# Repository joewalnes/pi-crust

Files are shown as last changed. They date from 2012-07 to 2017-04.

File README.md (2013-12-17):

Pi Crust
========

This is a PCB that brings sanity to Raspberry Pi headers.

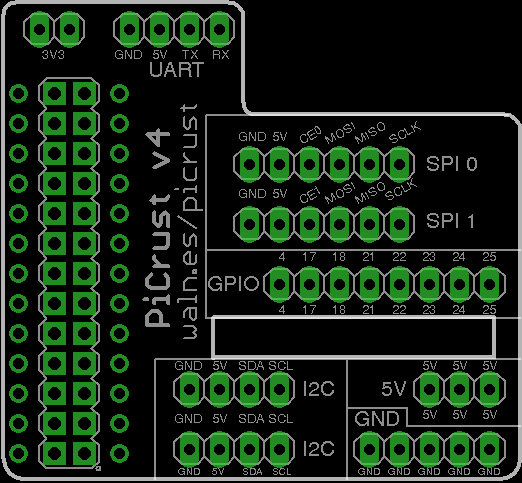
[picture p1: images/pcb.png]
Pi Crust PCB Layout


See [http://picru.st](http://picru.st) for more.

Features
--------

*   Really compact - sits *inside* the surface area of the Raspberry Pi and adds less than 2mm to the height. If you have a case for your Raspberry Pi, this board should fit inside it.
*   Pins are grouped together: GPIO, I2C, SPI, UART and power.
*   Every pin is clearly labelled.
*   Connections: 2 x SPI, 2 x I2C, 1 x UART, 8 x GPIO
*   Uses female headers instead of male headers - you can poke jumpers right in.
*   Lots of GND and 5V pins - you need those guys a lot. These pins are duplicated where it makes sense (e.g. within the UART, I2C and SPI groups).
*   All thru-hole components - you can solder it yourself.
*   Cheapety cheapy cheap.
*   Open source hardware.
*   [More photos here](http://todayimade.co/items/joe-walnes-made-a-tiny-breakout-board-for-raspberry-pi)

See [http://picru.st](http://picru.st) for more.

Bitdeli Badge (https://bitdeli.com/free "Bitdeli Badge")

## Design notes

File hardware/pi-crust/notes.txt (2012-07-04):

01: 3.3V (50 mA max)
02: 5V
06: GND

07: GPIO 4 (GPCLCK0)
11: GPIO 17
12: GPIO 18 (PWM)
13: GPIO 21
15: GPIO 22
16: GPIO 23
18: GPIO 24
22: GPIO 25

== I2C * 2 == order: g, 5v, sda, scl	
03: I2C SDA / GPIO 0
05: I2C SCL / GPIO 1

== UART . order: g, 5v, tx, rx
08: TX / GPIO 14
10: RX / GPIO 15

== SPI * 2 Select (g, v, CE1/CE0, mosi, miso, sclk)
26: SPI CE1_N / GPIO 7
24: SPI CE0_N / GPIO 8
21: SPI MISO / GPIO 9
19: SPI MOSI / GPIO 10
23: SPI SCLK / GPIO 11

04: DNC
09: DNC
14: DNC
17: DNC
20: DNC
25: DNC

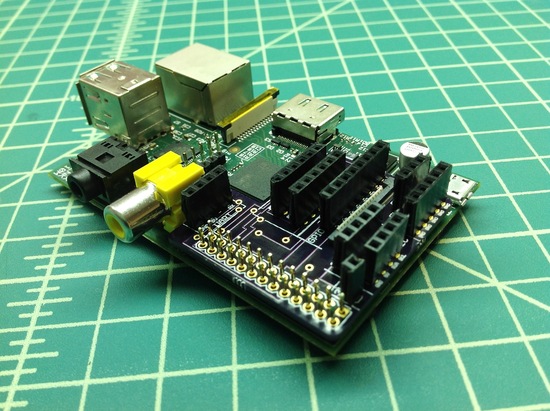
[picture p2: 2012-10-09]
images/prototype.jpg

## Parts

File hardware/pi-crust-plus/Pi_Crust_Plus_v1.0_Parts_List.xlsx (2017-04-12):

Part | Manufacturer | Quantity | Comment
MDF7-26D-2.54DSA(55) | Hirose | 1
40 pin 2.54mm female header |  | 1 | Plastic height - 8mm, metal height 8mm, square pins 0.64mm
1x2 2.54mm female header |  | 2
1x4 2.54mm female header |  | 5
1x6 2.54mm female header |  | 2
1x8 2.54mm female header |  | 1
1x9 2.54mm female header |  | 1
1x2 2.54mm male header |  | 1

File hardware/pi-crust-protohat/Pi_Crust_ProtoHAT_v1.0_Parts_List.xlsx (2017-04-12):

Part | Value | Device | Package
C1 | 100nF | C-EUC0805K | C0805K
CFG | 2 pin jumper, 2.54mm | PIN2_100 | PIN_W_2
R1 | 3k9 | R-EU_M0805 | M0805
R2 | 3k9 | R-EU_M0805 | M0805
R3 | 1k | R-EU_M0805 | M0805
U1 | CAT24C32 | EEPROM24 | SOIC8
Header | 10724 from www.4uconnector.com
Shunt for CFG | 2.54mm 2 pin shunt

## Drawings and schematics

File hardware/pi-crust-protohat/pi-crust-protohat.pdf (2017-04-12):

A

A

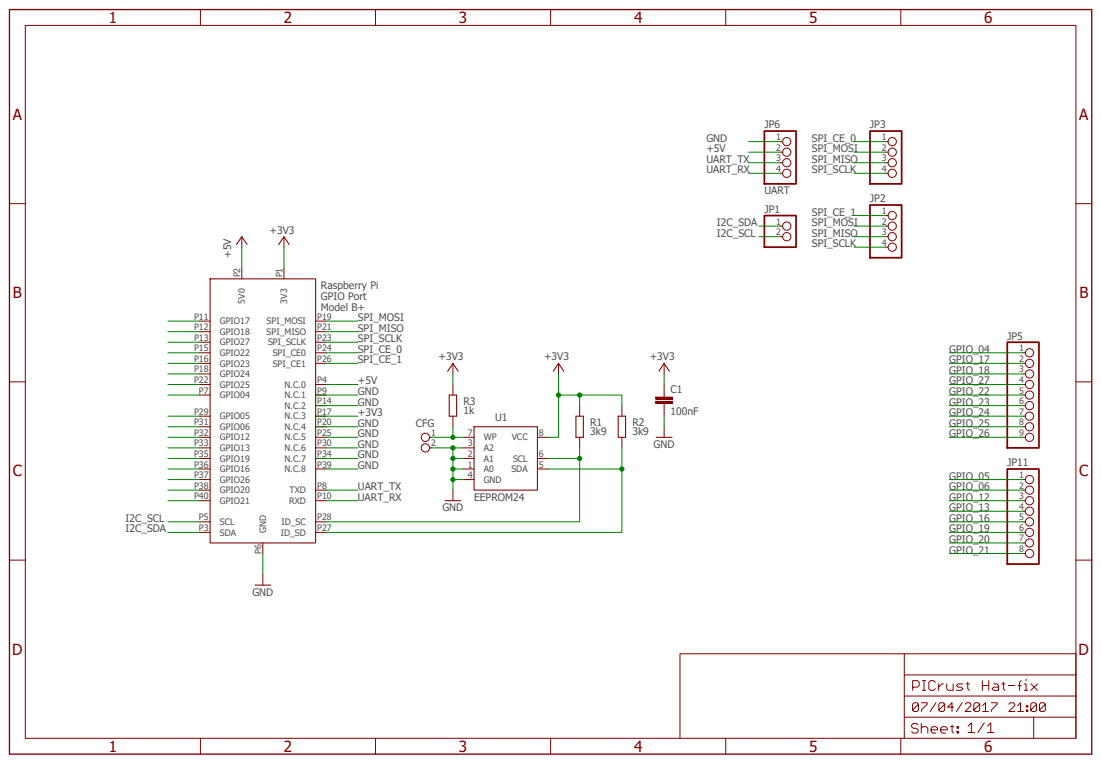
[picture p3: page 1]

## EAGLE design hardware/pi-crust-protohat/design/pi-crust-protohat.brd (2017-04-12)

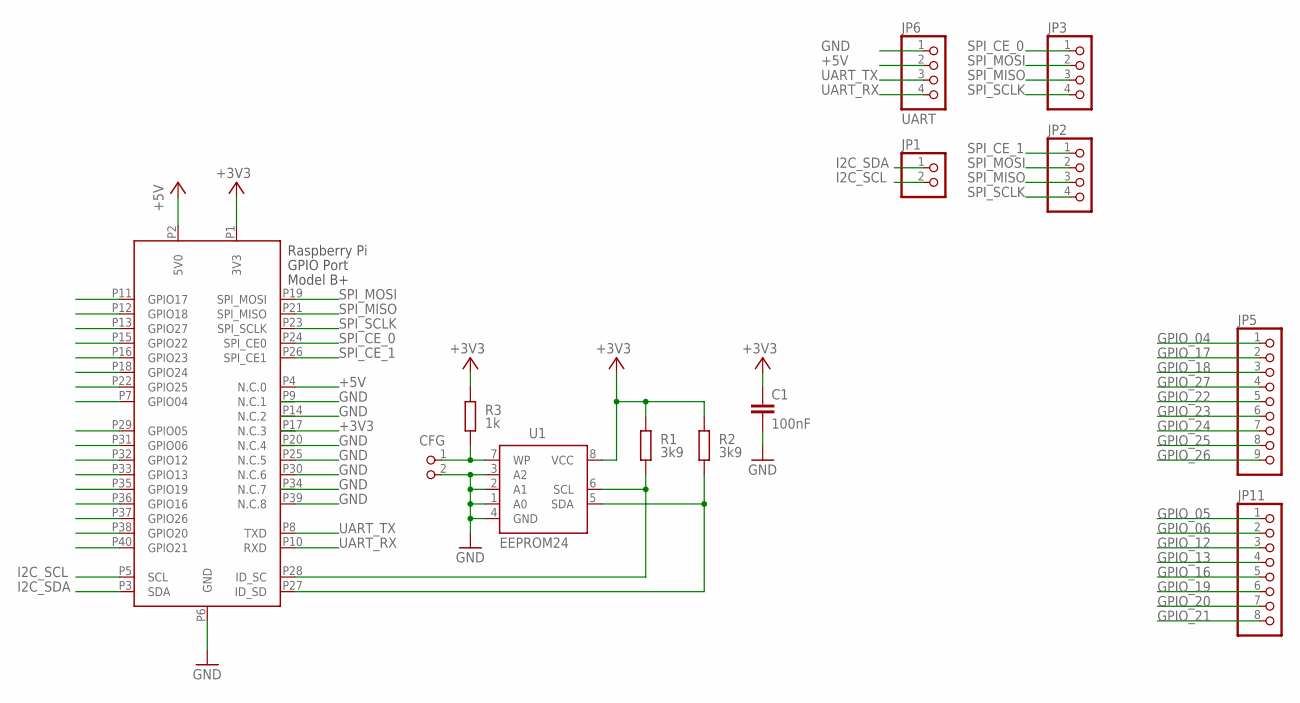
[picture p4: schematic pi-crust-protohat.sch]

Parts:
C1: 100nF; C0805K
CFG: PIN2_100; PIN_W_2
JP1: PINHD-1X2; 1X02
JP2, JP3: PINHD-1X4; 1X04
JP5: PINHD-1X9; 1X09
JP6: UART; 1X04
JP11: PINHD-1X8; 1X08
R1, R2: 3k9; M0805; TOLERANCE 5%
R3: 1k; M0805; TOLERANCE 5%
U1: EEPROM24; SOIC8
U$1: RASPI_BOARD_B+_SMD; RASPI_BOARD_B+_SMD_CONNECTOR

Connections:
+3V3: C1.1, R1.2, R2.2, R3.2, U1.8 (VCC), U$1.P1 (3V3)
+5V: JP6.2, U$1.P2 (5V0), U$1.P4 (N.C.0)
GND: C1.2, CFG.2, JP6.1, U1.1 (A0), U1.2 (A1), U1.3 (A2), U1.4 (GND), U$1.P6 (GND), U$1.P25 (N.C.5), U$1.P30 (N.C.6), U$1.P39 (N.C.8)
GPIO_04: JP5.1, U$1.P7 (GPIO04)
GPIO_05: JP11.1, U$1.P29 (GPIO05)
GPIO_06: JP11.2, U$1.P31 (GPIO06)
GPIO_12: JP11.3, U$1.P32 (GPIO12)
GPIO_13: JP11.4, U$1.P33 (GPIO13)
GPIO_16: JP11.5, U$1.P36 (GPIO16)
GPIO_17: JP5.2, U$1.P11 (GPIO17)
GPIO_18: JP5.3, U$1.P12 (GPIO18)
GPIO_19: JP11.6, U$1.P35 (GPIO19)
GPIO_20: JP11.7, U$1.P38 (GPIO20)
GPIO_21: JP11.8, U$1.P40 (GPIO21)
GPIO_22: JP5.5, U$1.P15 (GPIO22)
GPIO_23: JP5.6, U$1.P16 (GPIO23)
GPIO_24: JP5.7, U$1.P18 (GPIO24)
GPIO_25: JP5.8, U$1.P22 (GPIO25)
GPIO_26: JP5.9, U$1.P37 (GPIO26)
GPIO_27: JP5.4, U$1.P13 (GPIO27)
I2C_SCL: JP1.2, U$1.P5 (SCL)
I2C_SDA: JP1.1, U$1.P3 (SDA)
unnamed: CFG.1, R3.1, U1.7 (WP)
unnamed: R1.1, U1.6 (SCL), U$1.P28 (ID_SC)
unnamed: R2.1, U1.5 (SDA), U$1.P27 (ID_SD)
SPI_CE_0: JP3.1, U$1.P24 (SPI_CE0)
SPI_CE_1: JP2.1, U$1.P26 (SPI_CE1)
SPI_MISO: JP2.3, JP3.3, U$1.P21 (SPI_MISO)
SPI_MOSI: JP2.2, JP3.2, U$1.P19 (SPI_MOSI)
SPI_SCLK: JP2.4, JP3.4, U$1.P23 (SPI_SCLK)
UART_RX: JP6.4, U$1.P10 (RXD)
UART_TX: JP6.3, U$1.P8 (TXD)

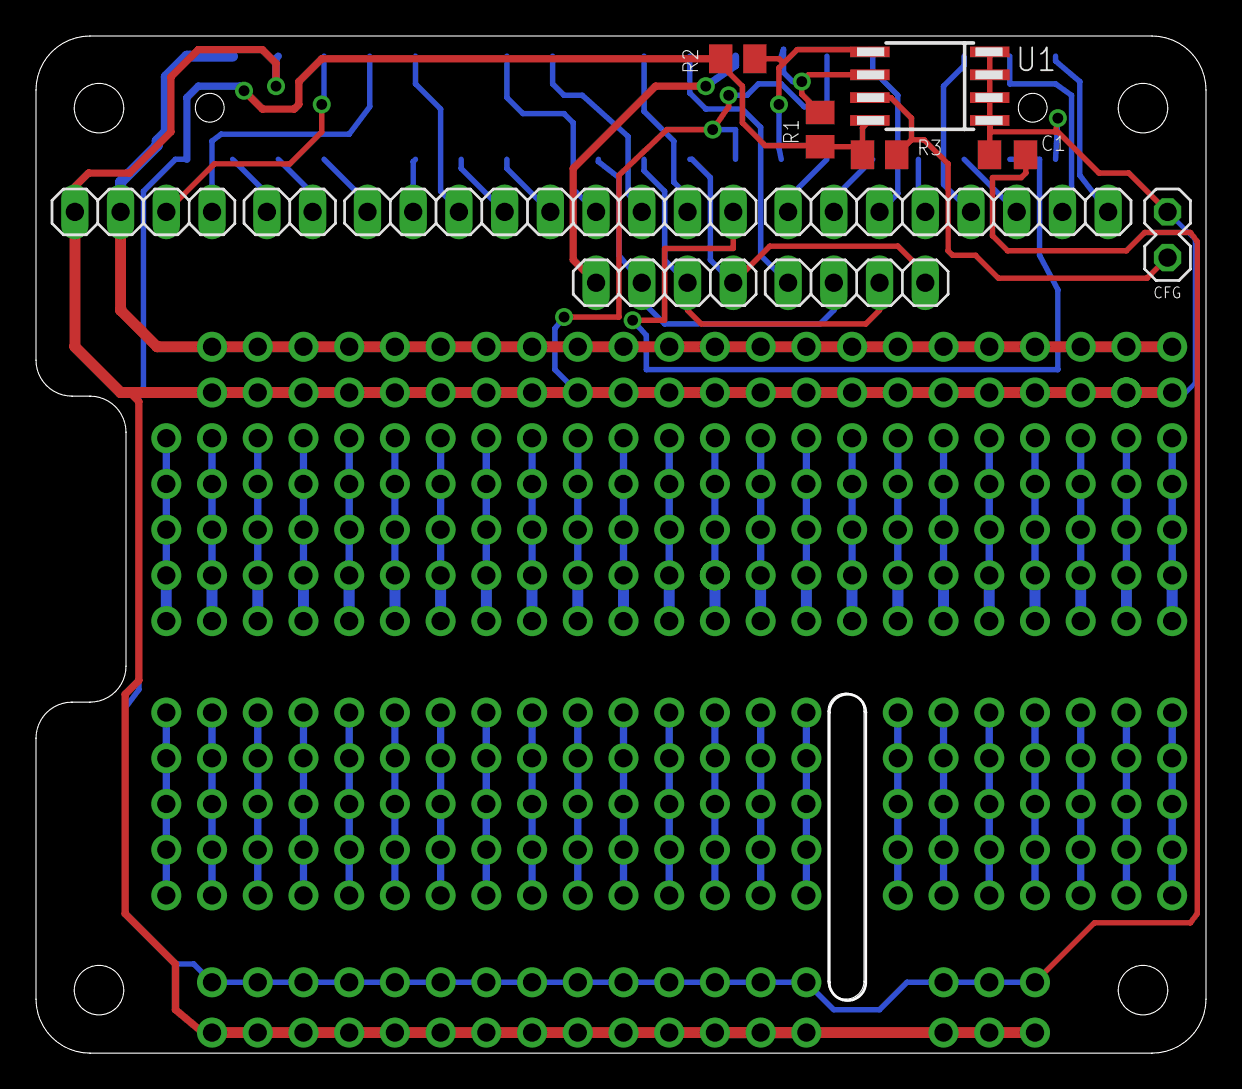
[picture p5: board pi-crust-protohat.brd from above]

Board: 2 copper layers, 65.0 x 56.5 mm, 13 parts (0 on the bottom side), 32 nets.

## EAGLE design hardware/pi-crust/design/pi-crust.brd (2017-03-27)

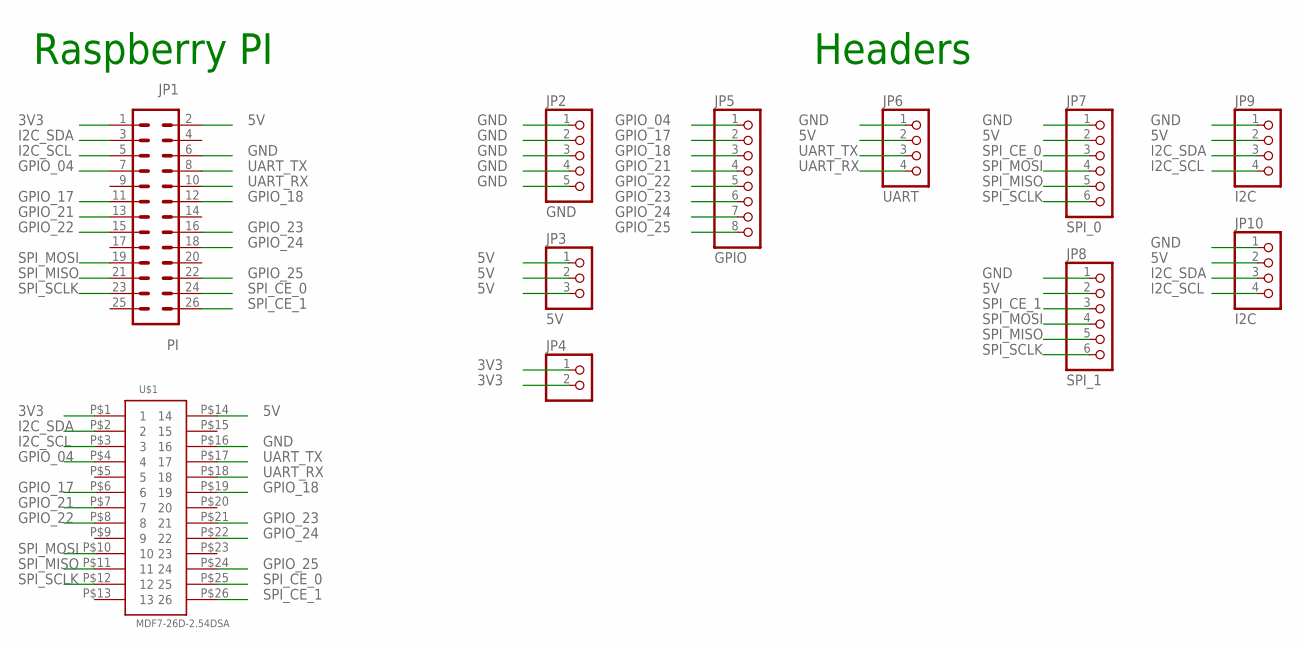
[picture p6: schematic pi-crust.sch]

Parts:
JP1: PI; MA13-2
JP2: GND; 1X05
JP3: 5V; 1X03
JP4: PINHD-1X2; 1X02
JP5: GPIO; 1X08
JP6: UART; 1X04
JP7: SPI_0; 1X06
JP8: SPI_1; 1X06
JP9, JP10: I2C; 1X04
U$1: MDF7-26D-2.54DSA

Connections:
3V3: JP1.1, JP4.1, JP4.2, U$1.P$1 (1)
5V: JP1.2, JP3.1, JP3.2, JP3.3, JP6.2, JP7.2, JP8.2, JP9.2, JP10.2, U$1.P$14 (14)
GND: JP1.6, JP2.1, JP2.2, JP2.3, JP2.4, JP2.5, JP6.1, JP7.1, JP8.1, JP9.1, JP10.1, U$1.P$16 (16)
GPIO_04: JP1.7, JP5.1, U$1.P$4 (4)
GPIO_17: JP1.11, JP5.2, U$1.P$6 (6)
GPIO_18: JP1.12, JP5.3, U$1.P$19 (19)
GPIO_21: JP1.13, JP5.4, U$1.P$7 (7)
GPIO_22: JP1.15, JP5.5, U$1.P$8 (8)
GPIO_23: JP1.16, JP5.6, U$1.P$21 (21)
GPIO_24: JP1.18, JP5.7, U$1.P$22 (22)
GPIO_25: JP1.22, JP5.8, U$1.P$24 (24)
I2C_SCL: JP1.5, JP9.4, JP10.4, U$1.P$3 (3)
I2C_SDA: JP1.3, JP9.3, JP10.3, U$1.P$2 (2)
SPI_CE_0: JP1.24, JP7.3, U$1.P$25 (25)
SPI_CE_1: JP1.26, JP8.3, U$1.P$26 (26)
SPI_MISO: JP1.21, JP7.5, JP8.5, U$1.P$11 (11)
SPI_MOSI: JP1.19, JP7.4, JP8.4, U$1.P$10 (10)
SPI_SCLK: JP1.23, JP7.6, JP8.6, U$1.P$12 (12)
UART_RX: JP1.10, JP6.4, U$1.P$18 (18)
UART_TX: JP1.8, JP6.3, U$1.P$17 (17)

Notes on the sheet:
Raspberry PI
Headers

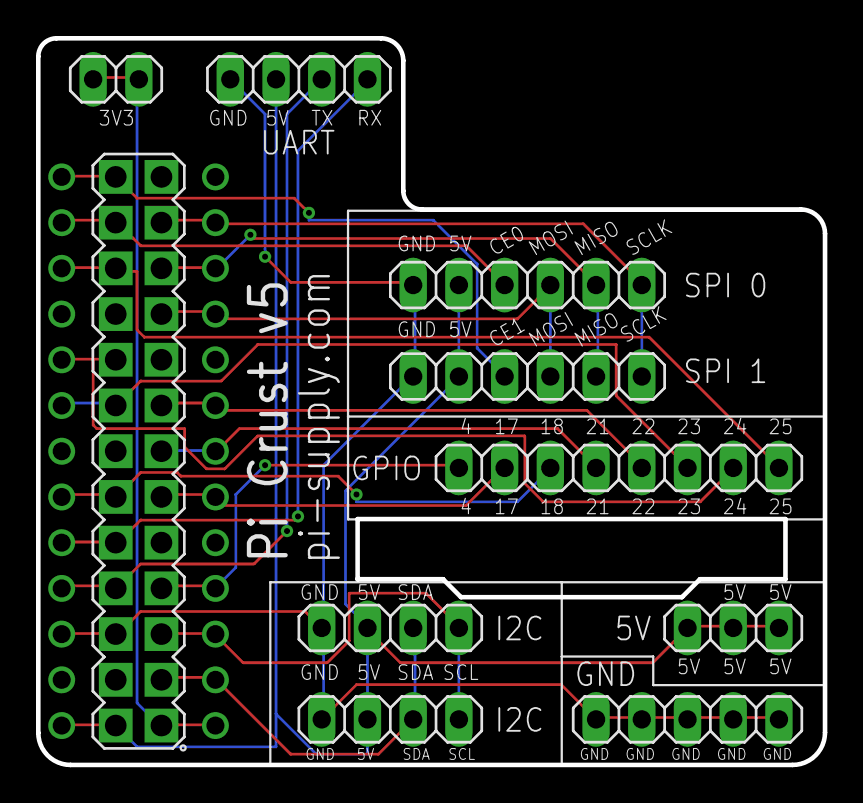
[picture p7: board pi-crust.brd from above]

Board: 2 copper layers, 43.7 x 40.4 mm, 11 parts (1 on the bottom side), 20 nets.

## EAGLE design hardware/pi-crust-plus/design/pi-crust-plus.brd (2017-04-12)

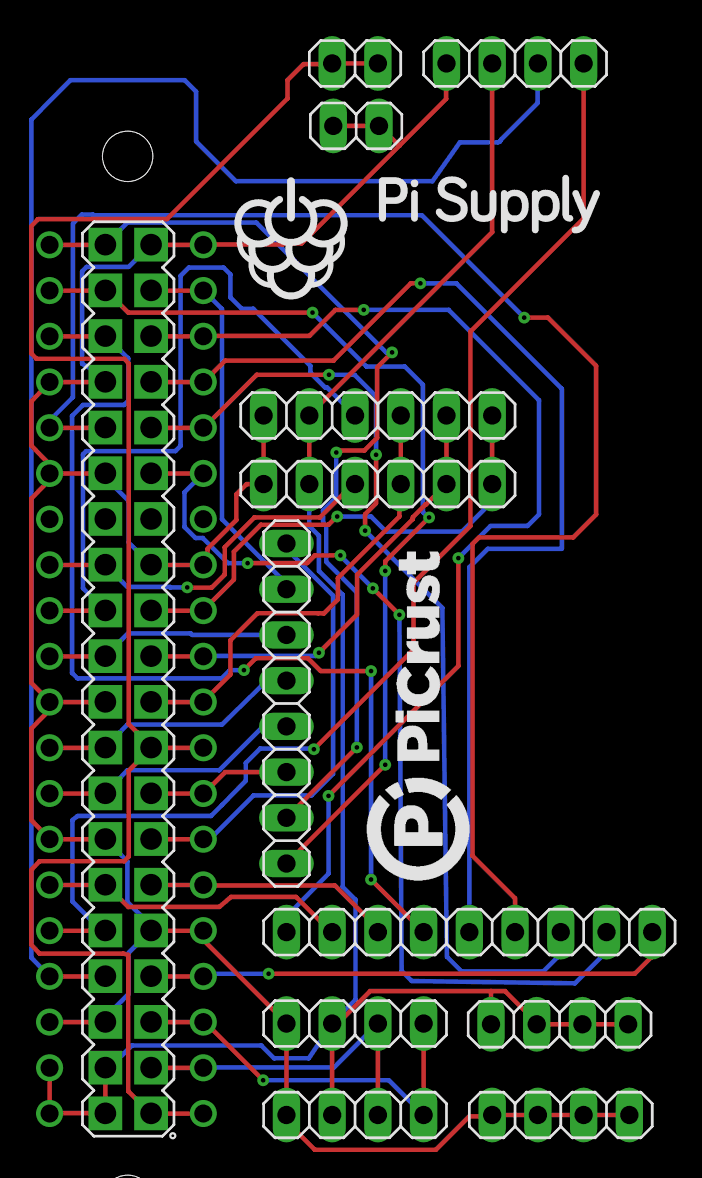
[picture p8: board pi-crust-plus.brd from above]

Board: 2 copper layers, 13 parts (1 on the bottom side), 29 nets.

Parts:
JP1: GND; 1X04
JP2: GND; 1X02
JP3: 5V; 1X04
JP4: 3V3; 1X02
JP5: 1X09
JP6: UART; 1X04
JP7: SPI 0; 1X06
JP8: SPI 1; 1X06
JP9, JP10: I2C; 1X04
JP11: 1X08
SV1: MA20-2
U$1: MDF7-40D-2.54DSA

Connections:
3V3: JP4.1, JP4.2, SV1.1, SV1.17, U$1.P$1, U$1.P$9
5V: JP3.1, JP3.2, JP3.3, JP3.4, JP6.2, JP7.2, JP8.2, JP9.2, JP10.2, SV1.2, SV1.4, U$1.P$21, U$1.P$22
GND: JP1.1, JP1.2, JP1.3, JP1.4, JP2.1, JP2.2, JP6.1, JP7.1, JP8.1, JP9.1, JP10.1, SV1.6, SV1.9, SV1.14, SV1.20, SV1.25, SV1.30, SV1.34, SV1.39, U$1.P$5, U$1.P$13, U$1.P$20, U$1.P$23, U$1.P$27, U$1.P$30, U$1.P$35, U$1.P$37
GPIO_04: JP5.1, SV1.7, U$1.P$4
GPIO_05: JP5.2, SV1.29, U$1.P$15
GPIO_06: JP5.3, SV1.31, U$1.P$16
GPIO_12: JP5.4, SV1.32, U$1.P$36
GPIO_13: JP5.5, SV1.33, U$1.P$17
GPIO_16: JP5.6, SV1.36, U$1.P$38
GPIO_17: JP5.7, SV1.11, U$1.P$6
GPIO_18: JP5.8, SV1.12, U$1.P$26
GPIO_19: JP5.9, SV1.35, U$1.P$18
GPIO_20: JP11.1, SV1.38, U$1.P$39
GPIO_21: JP11.2, SV1.40, U$1.P$40
GPIO_22: JP11.3, SV1.15, U$1.P$8
GPIO_23: JP11.4, SV1.16, U$1.P$28
GPIO_24: JP11.5, SV1.18, U$1.P$29
GPIO_25: JP11.6, SV1.22, U$1.P$31
GPIO_26: JP11.7, SV1.37, U$1.P$19
GPIO_27: JP11.8, SV1.13, U$1.P$7
I2C_SCL: JP9.4, JP10.4, SV1.5, U$1.P$3
I2C_SDA: JP9.3, JP10.3, SV1.3, U$1.P$2
SPI_CE_0: JP7.3, SV1.24, U$1.P$32
SPI_CE_1: JP8.3, SV1.26, U$1.P$33
SPI_MISO: JP7.5, JP8.5, SV1.21, U$1.P$11
SPI_MOSI: JP7.4, JP8.4, SV1.19, U$1.P$10
SPI_SCLK: JP7.6, JP8.6, SV1.23, U$1.P$12
UART_RX: JP6.4, SV1.10, U$1.P$25
UART_TX: JP6.3, SV1.8, U$1.P$24

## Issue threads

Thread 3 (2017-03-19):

raspberry pi 2+ and 3 version?

schlichtanders, 2017-03-19:
This project sounds awesome, however the board seems to fit to the old raspberry pi version only

Any plans to put this to the next level for never raspberry pi versions?

shawaj, 2017-03-19:
We've got a design but just have not released it yet as we've been too busy.

But we will get it out of the door soon.

Thanks

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

schlichtanders, 2017-03-20:
that sounds great!!
looking forward to it

shawaj, 2017-03-20:
Yep, looking at it today. See what needs sorting before manufacture :-)

shawaj, 2017-03-27:
Have fixed this with https://github.com/joewalnes/pi-crust/commit/4fd7ba9fa64b0fee1ba657ba59e217d132ff00e8

Will be starting to produce these in the next month or so. And then will release via https://www.pi-supply.com

shawaj, 2017-04-12:
Closing this issue now - but keep an eye on our twitter feed :-)

[https://twitter.com/PiSupply/status/852243668845174784](https://twitter.com/PiSupply/status/852243668845174784)

Closed 2017-04-12.

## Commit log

2012-07-04 First cut of schematic
    [pi-crust.brd, pi-crust.sch]
2012-07-04 Makefile to generate and view gerbers
2012-07-04 Schematic jumpers all have values. Eagle electrical rule check now passes
    [pi-crust.brd, pi-crust.sch]
2012-07-04 Improved schematic layout
    [pi-crust.brd, pi-crust.sch]
2012-07-04 Rearrange labels and make a bit more space for routing paths
    [pi-crust.brd]
2012-07-05 Removed airflow hole (made board unroutable), mitred edges and routed wires.
    [pi-crust.brd]
2012-07-05 Added labels and section dividers to silkscreen layer
    [pi-crust.brd]
2012-07-05 Added PCB image screenshot
2012-07-05 Added parts list and assembly instructions.
2012-07-06 Created custom part for Pi connector, with drills that fit the pin insert components.
    [pi-crust.brd, pi-crust.sch]
2012-07-10 Manually routed by Mercedes
    [pi-crust.brd, pi-crust.sch]
2012-07-10 Moved all labels from tValues to tNames layer, so they appear on the silkscreen.
    [pi-crust.brd]
2012-08-28 Added marks on bottom to show where to attach support feet.
    [pi-crust.brd]
2012-08-28 Moved one of the vias so its not so close to the headers.
    [pi-crust.brd]
2012-08-28 Elongate board slot, as it was a wee bit too short.
    [pi-crust.brd]
2012-08-30 Increased diameter of solder pads around 26 pin connectors to make it easier to solder inserts.
2012-08-30 PiCrust V2:
    * Made 26 pin connector pads square, so it's easy to dab solder over
    the edges of the pin inserts.
    * Vias are smaller and tented.
    * Minor re-routing around some tight areas.
    * Added text to silk screen.
    [pi-crust.brd, pi-crust.sch]
2012-09-18 v3 board. With Hirose 26 pin connector.
    [pi-crust.brd, pi-crust.sch]
2012-10-09 V4: Replaced single 3V3 header with a double. Actually makes it cheaper to make and a 2nd connector is always handy. Shuffled the UART along a little.
    [pi-crust.brd, pi-crust.sch]
2012-10-09 Updated instructions and BOM
2012-10-26 Changed shape of hole to accomodate new DSI connector cover on RPi rev 2.
    [pi-crust.brd, pi-crust.sch]
2012-10-28 Fixed silkscreen text
    [pi-crust.brd]
2012-10-31 Automate gerber export. Just run make.
2013-01-03 Dont include solder paste layers in gerbers - not used.
2017-03-27 reorganise, add gerbers, add picrust plus and protohat
    reorganise, add gerbers, add picrust plus and protohat
    [Pi_Crust_ProtoHAT_v1.0_Parts_List.xlsx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]
2017-03-27 update picrust original design
    update picrust original design
    [pi-crust.brd]
2017-04-12 update hardware designs for plus and protohat
    update hardware designs for plus and protohat
    [Pi_Crust_Plus_v1.0_Parts_List.xlsx, Pi_Crust_ProtoHAT_v1.0_Parts_List.xlsx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]
